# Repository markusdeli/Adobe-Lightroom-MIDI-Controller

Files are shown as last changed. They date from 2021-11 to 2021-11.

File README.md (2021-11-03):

# Adobe-Lightroom-MIDI-Controller
Custom wireless MIDI controller for picture editing in Adobe Lightroom.
Using BLE for communication between controller and receiver. 
Color encoders can be built out of 9mm mouse encoders oder KY-040.
All .stl Files needed can be found in the folder "3D-Models".
Sofware for Interpreting MIDI signals: https://github.com/rsjaffe/MIDI2LR/releases

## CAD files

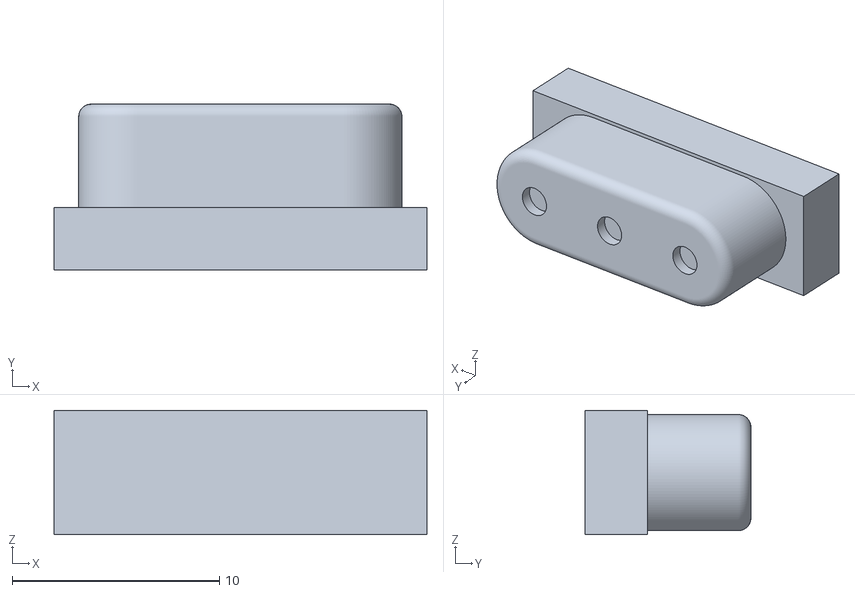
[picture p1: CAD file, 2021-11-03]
3D-models/b1.stl
18.0 x 8.00 x 6.00

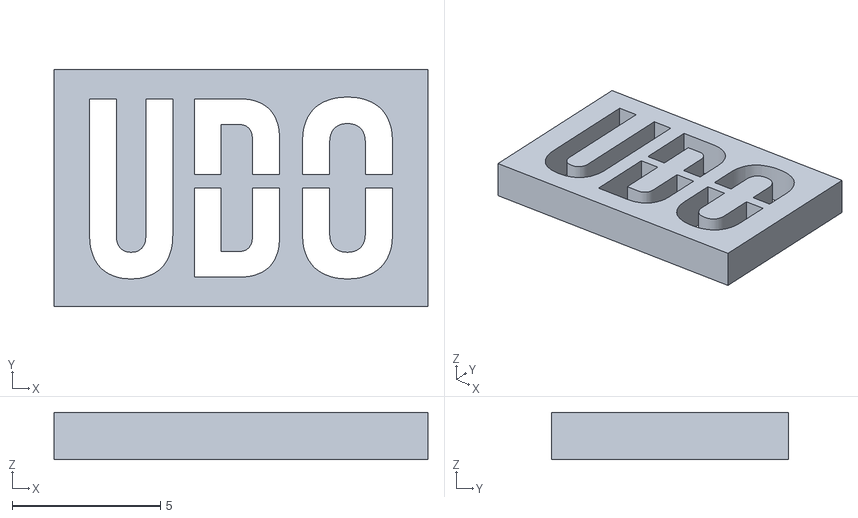
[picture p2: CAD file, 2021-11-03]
3D-models/1UDO.stl
12.6 x 8.00 x 1.60

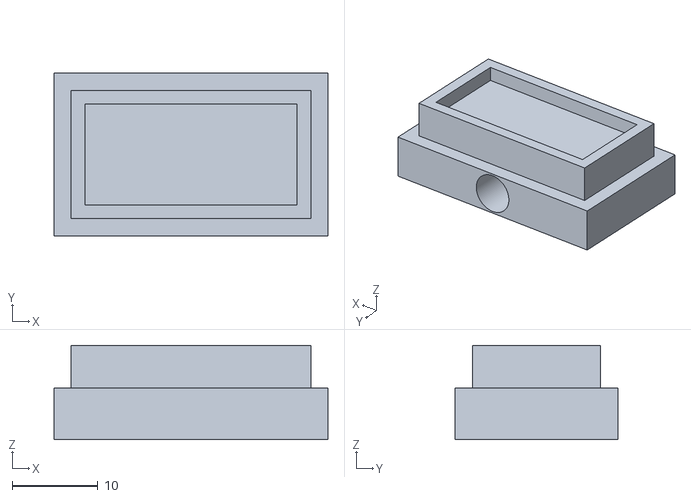
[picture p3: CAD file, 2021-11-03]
3D-models/buttonMIDimaxi.stl
32.0 x 19.0 x 11.0

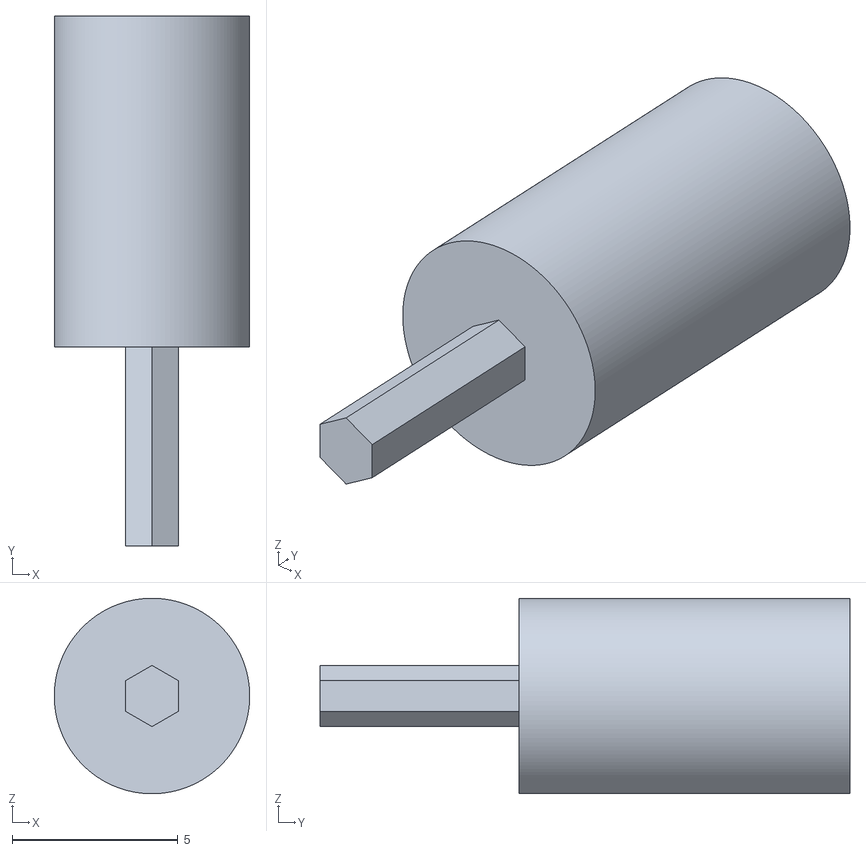
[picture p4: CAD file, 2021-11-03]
3D-models/mouse wheel shaft.stl
5.90 x 16.0 x 5.90

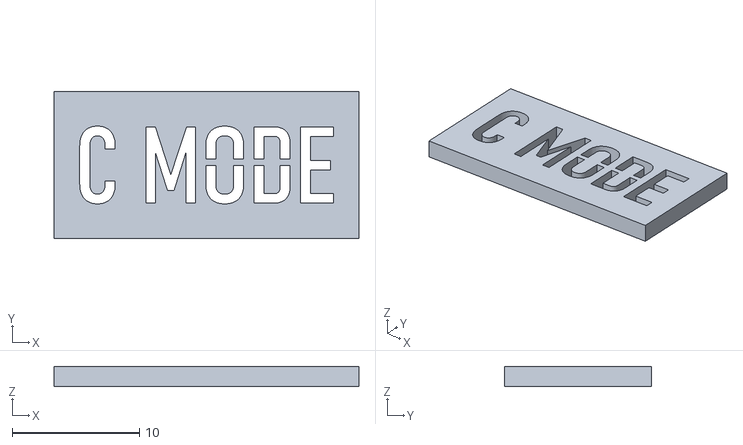
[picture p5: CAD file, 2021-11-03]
3D-models/1CMODE.stl
24.0 x 11.6 x 1.60

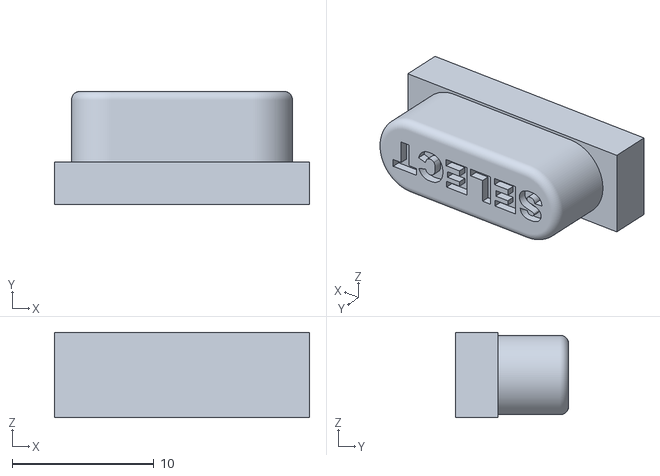
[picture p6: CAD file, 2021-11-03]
3D-models/b3.stl
18.0 x 8.00 x 6.00

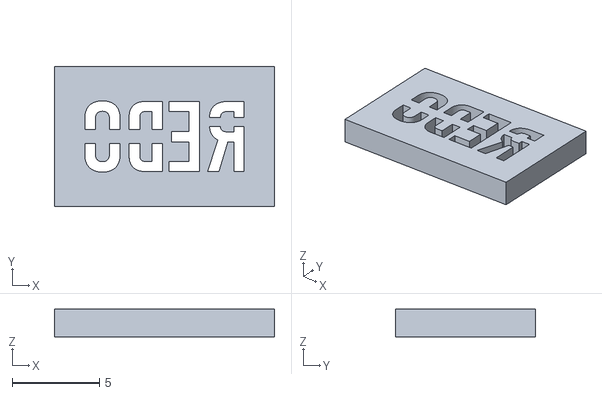
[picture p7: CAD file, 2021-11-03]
3D-models/redoMIDI.stl
12.6 x 8.00 x 1.60

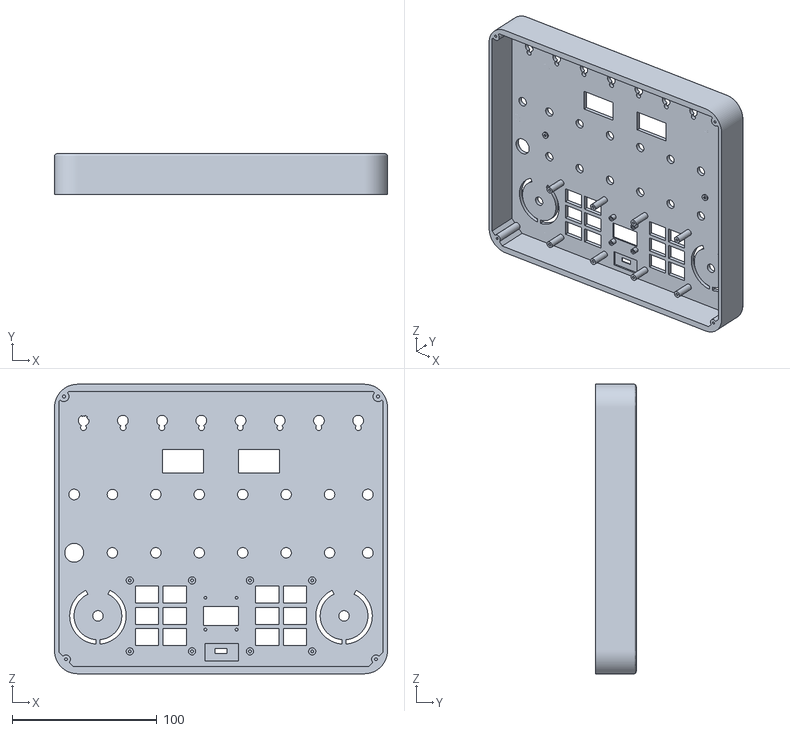
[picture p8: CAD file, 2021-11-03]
3D-models/midiv8.stl
230.0 x 28.0 x 200.0

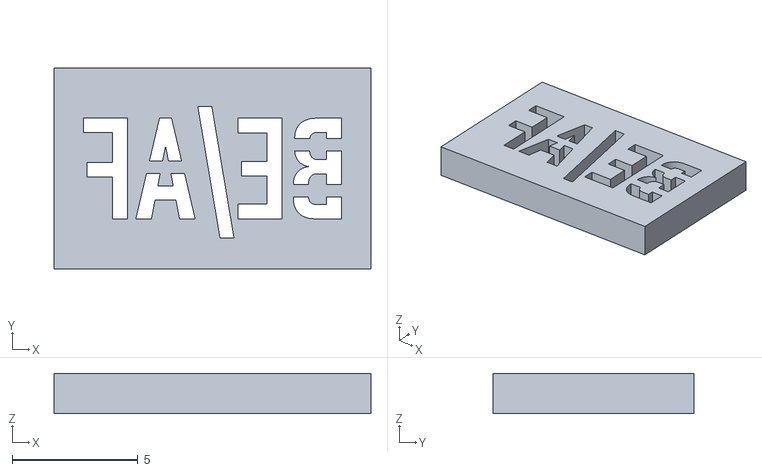
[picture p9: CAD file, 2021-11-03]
3D-models/beafMIDI.stl
12.6 x 8.00 x 1.60

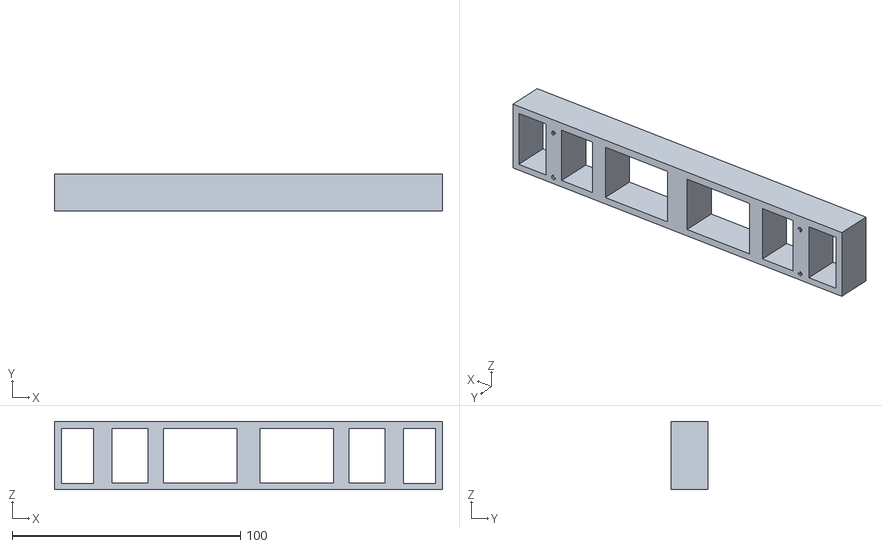
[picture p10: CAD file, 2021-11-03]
3D-models/block.stl
170.0 x 16.0 x 30.0

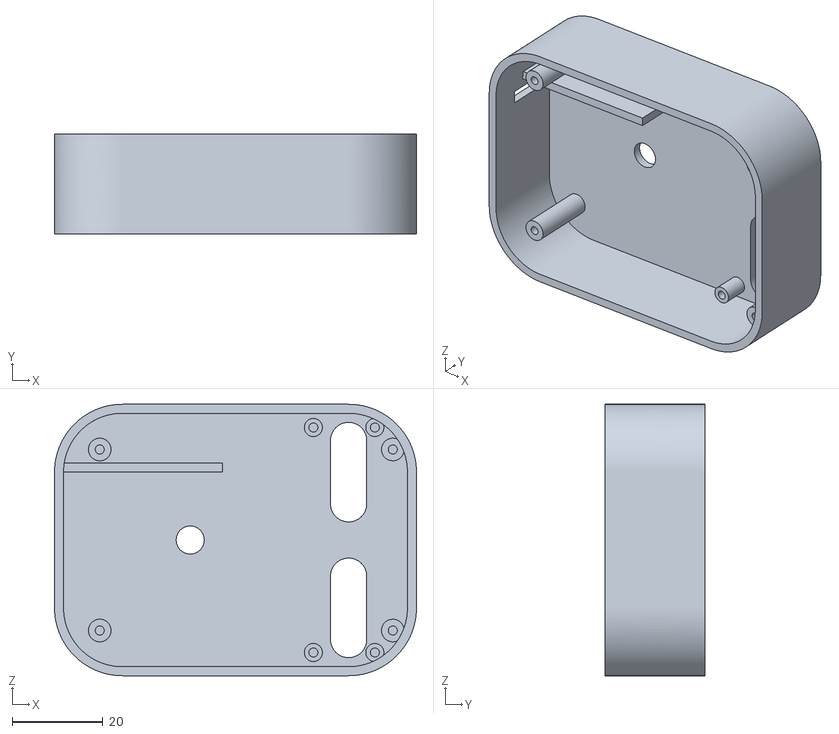
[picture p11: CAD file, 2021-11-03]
3D-models/topPiece.stl
80.0 x 22.0 x 60.0

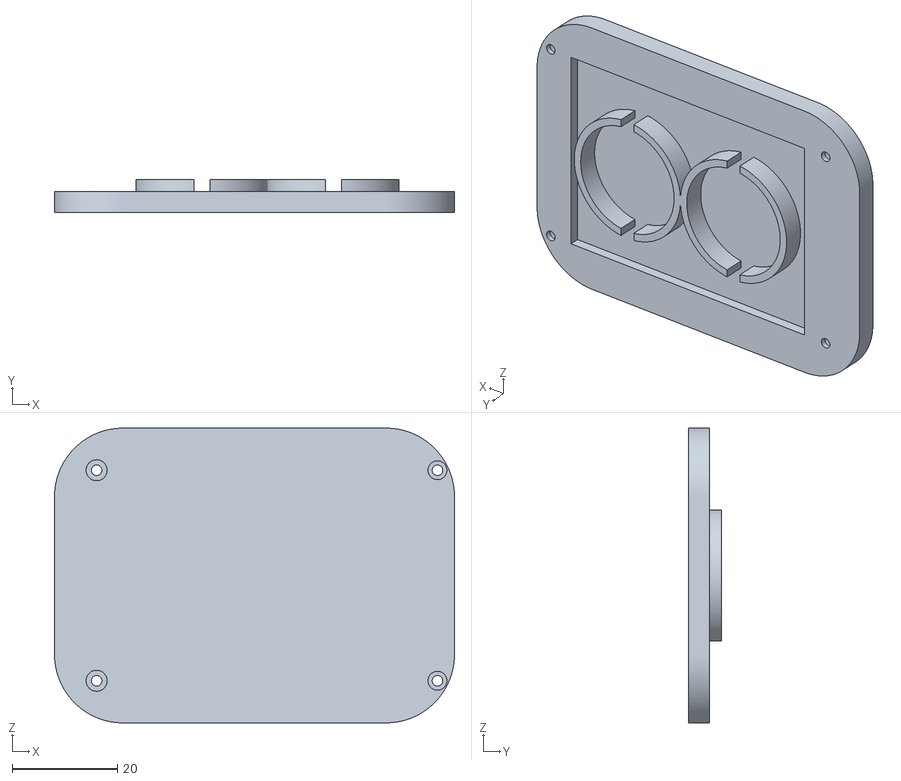
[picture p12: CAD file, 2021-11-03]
3D-models/botomPiece.stl
76.0 x 6.20 x 56.0

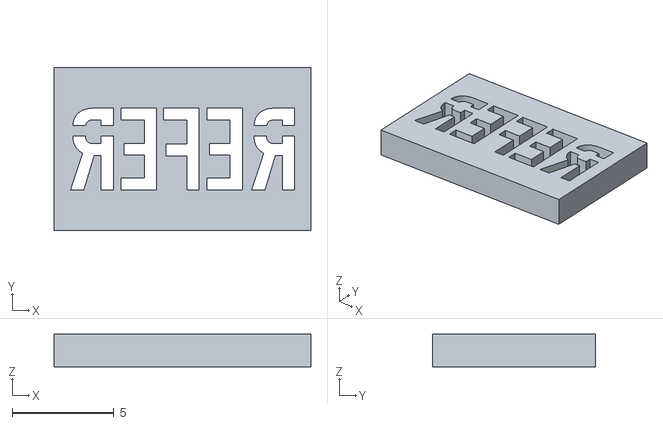
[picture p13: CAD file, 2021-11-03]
3D-models/referMIDI.stl
12.6 x 8.00 x 1.60

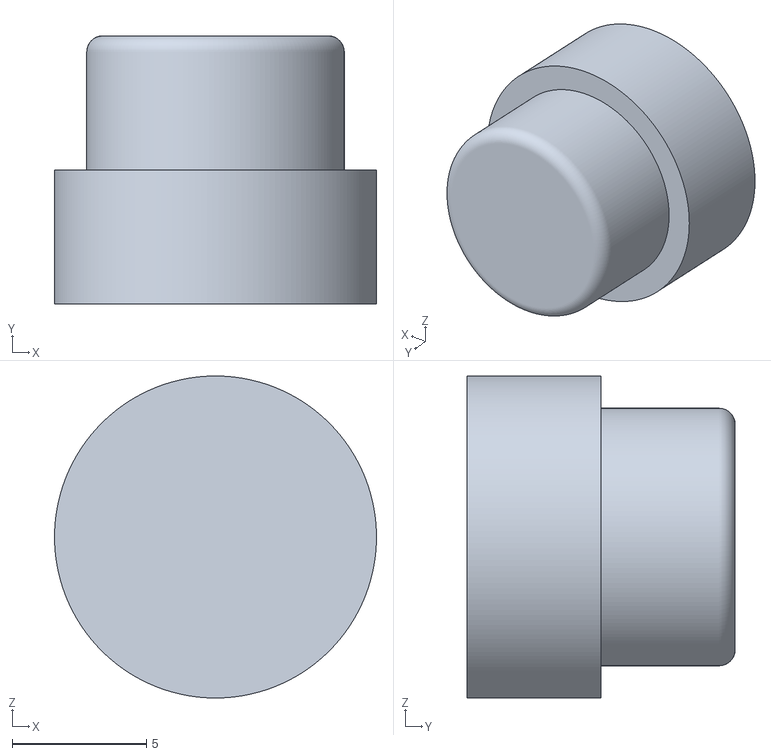
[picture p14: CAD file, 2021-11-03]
3D-models/button.stl
12.0 x 10.0 x 12.0

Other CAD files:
3D-models/1BEF.stl
3D-models/PAS.stl
3D-models/1MODE.stl
3D-models/DongleBottom.stl
3D-models/1M1.stl
3D-models/1M2.stl
3D-models/1RDO.stl
3D-models/1REF.stl
3D-models/BRU.stl
3D-models/BW.stl
3D-models/COP.stl
3D-models/DongleTop.stl
3D-models/InlayTopMIDI.stl
3D-models/RAD.stl
3D-models/REP.stl
3D-models/b2.stl
3D-models/buttonRotary.stl
3D-models/buttonklein.stl
3D-models/buttonnichtsoklein.stl
3D-models/color encoder.stl
3D-models/encoderKnobMaxiMIDI.stl
3D-models/encoderMAXIMIDI.stl
3D-models/encoderbracketmidi.stl
3D-models/encoderfillMIDI.stl
3D-models/fillMIDIEnc.stl
3D-models/inlayWheelLEDMIDI.stl
3D-models/kabelkammmidi.stl
3D-models/midicasetop.stl
3D-models/midicontrollerv1.stl
3D-models/midiencoderwheel.stl
3D-models/mouseshaftMIDI.stl
3D-models/stütze buttonMIDI.stl
3D-models/undoMIDI.stl

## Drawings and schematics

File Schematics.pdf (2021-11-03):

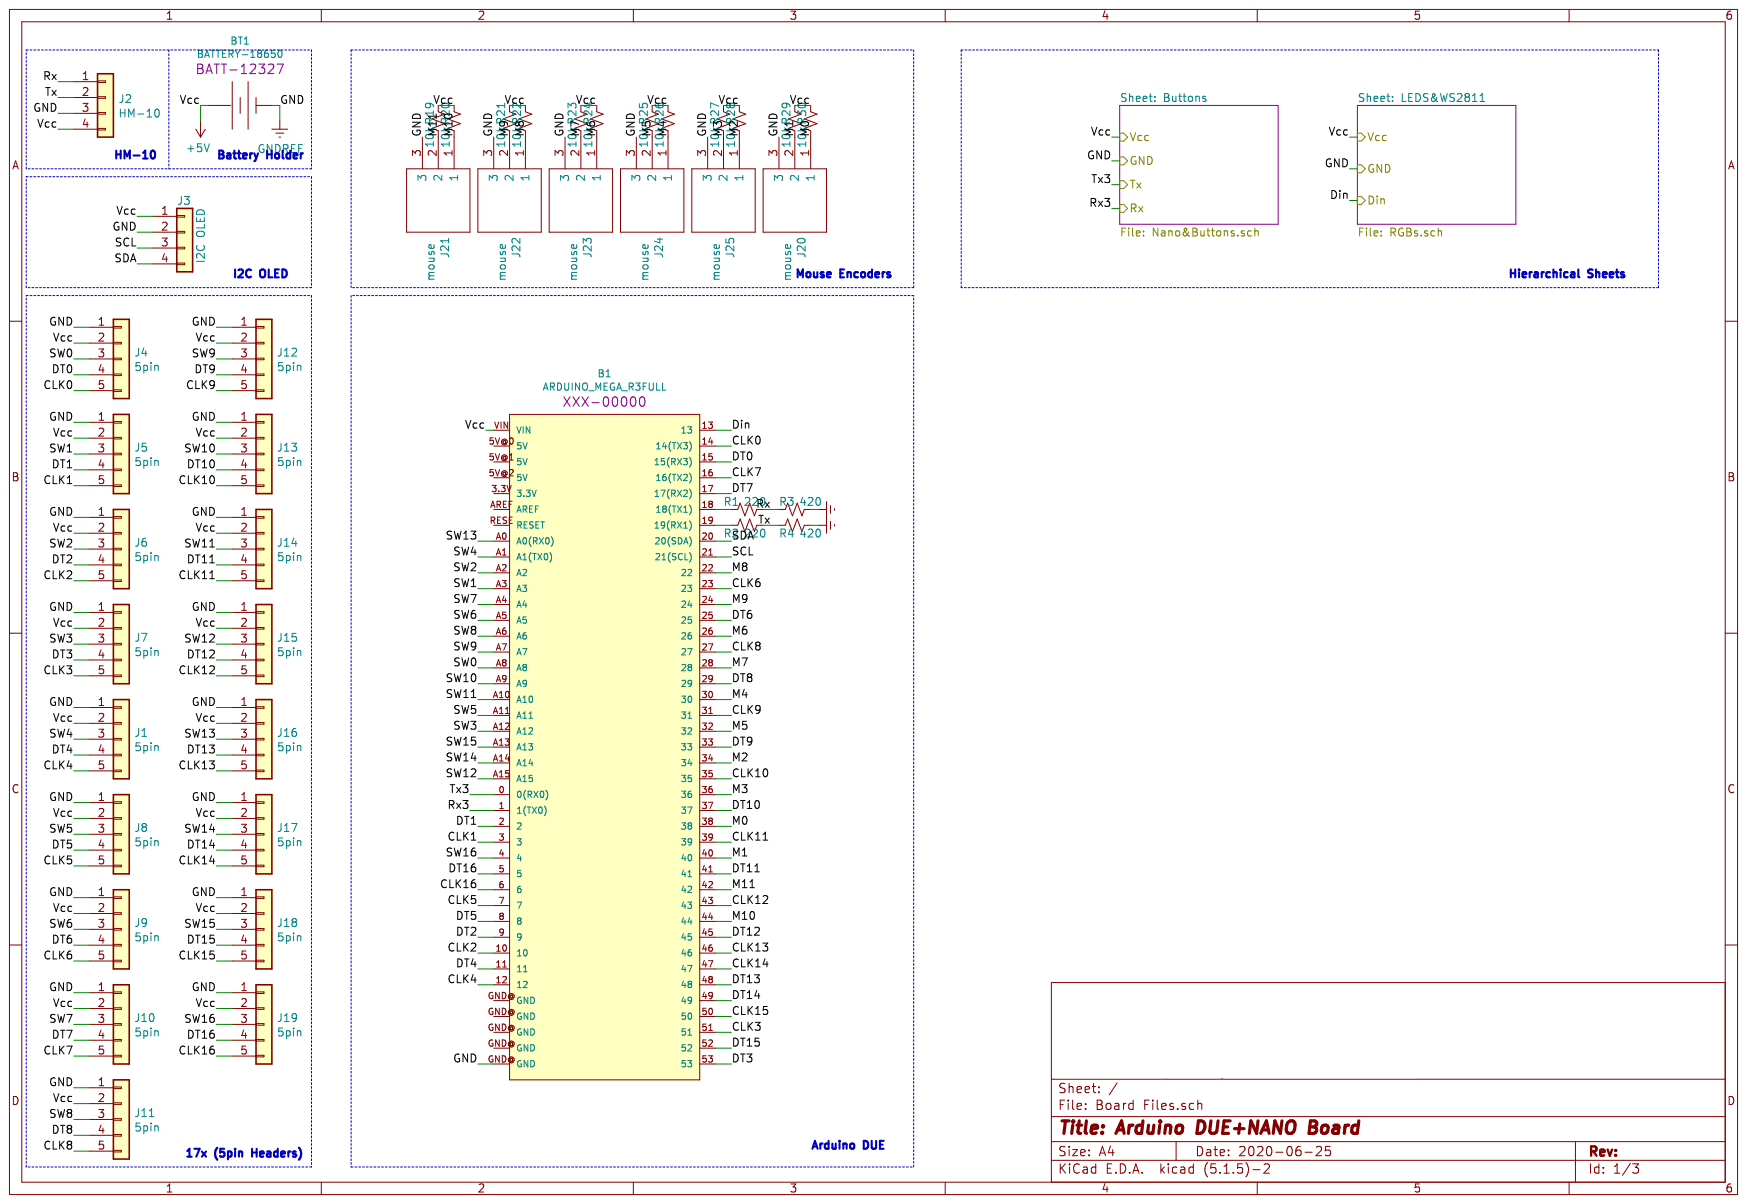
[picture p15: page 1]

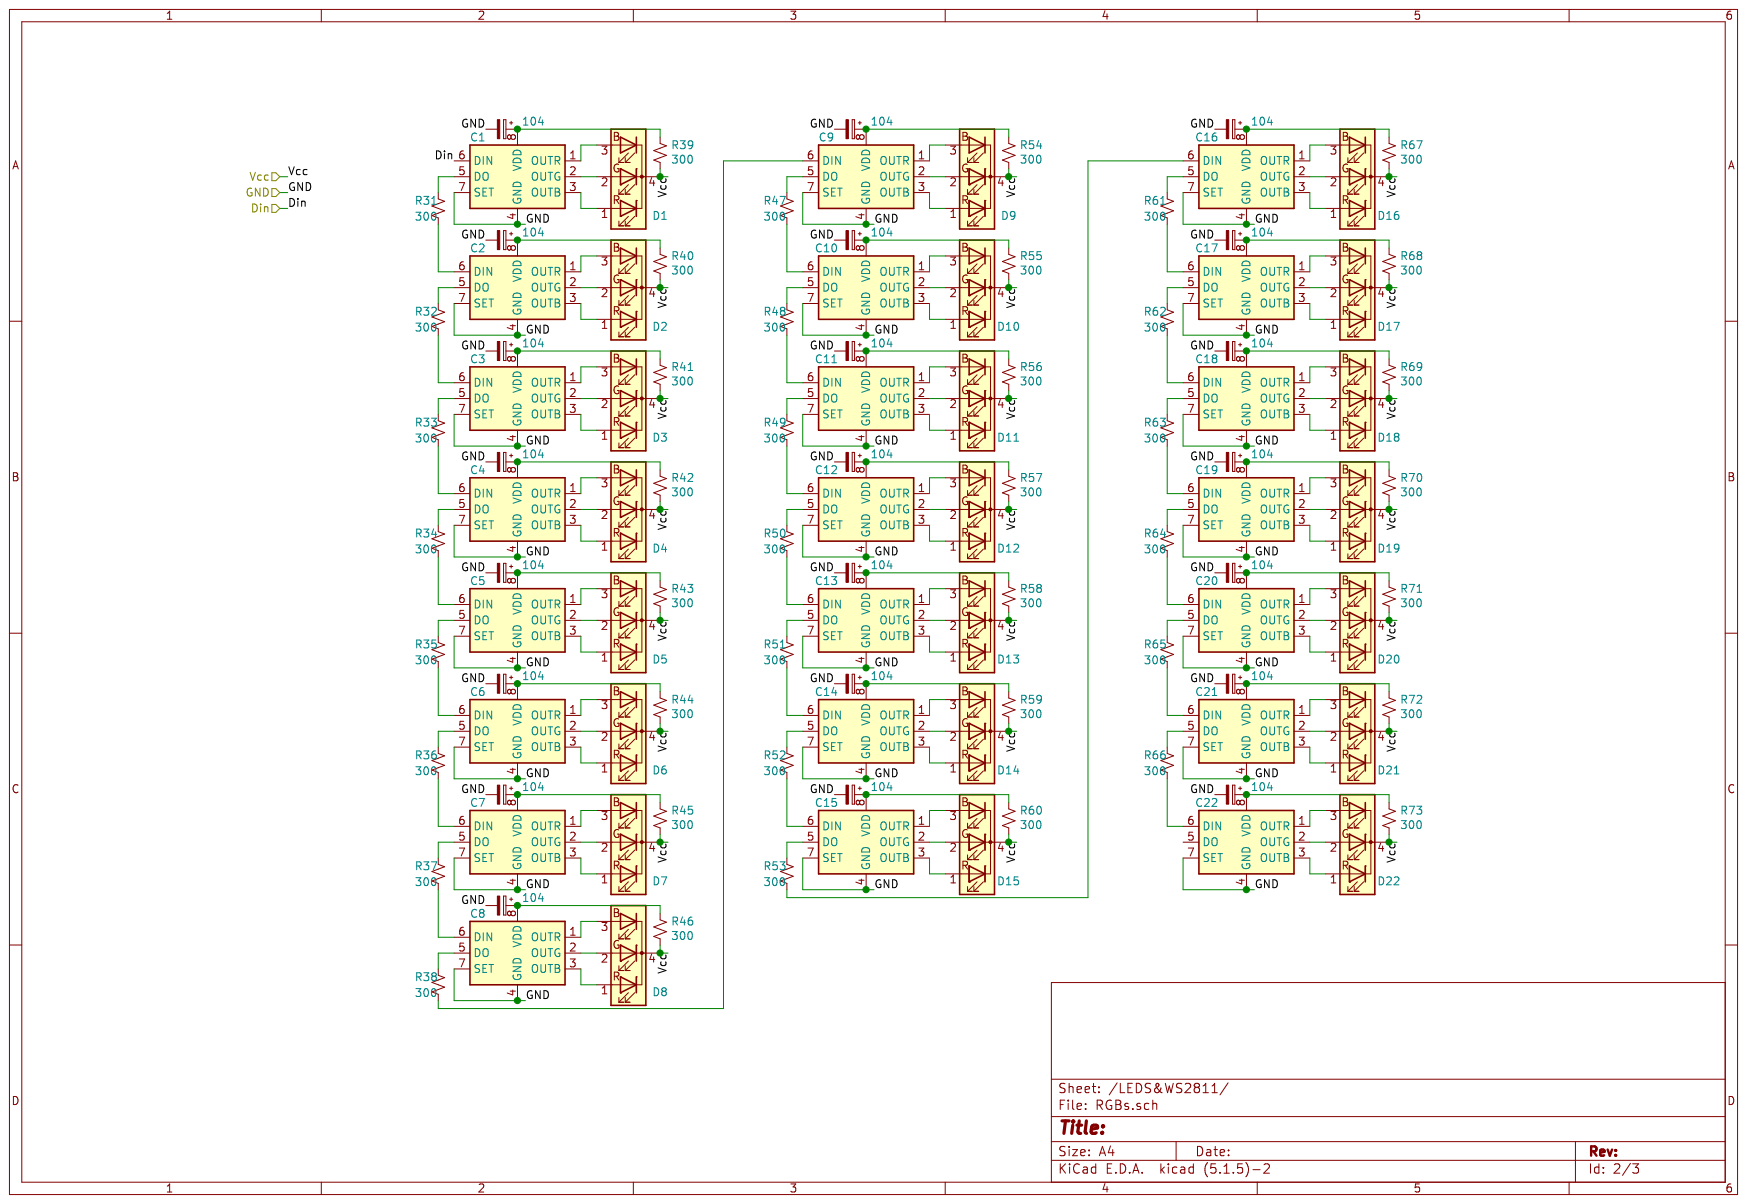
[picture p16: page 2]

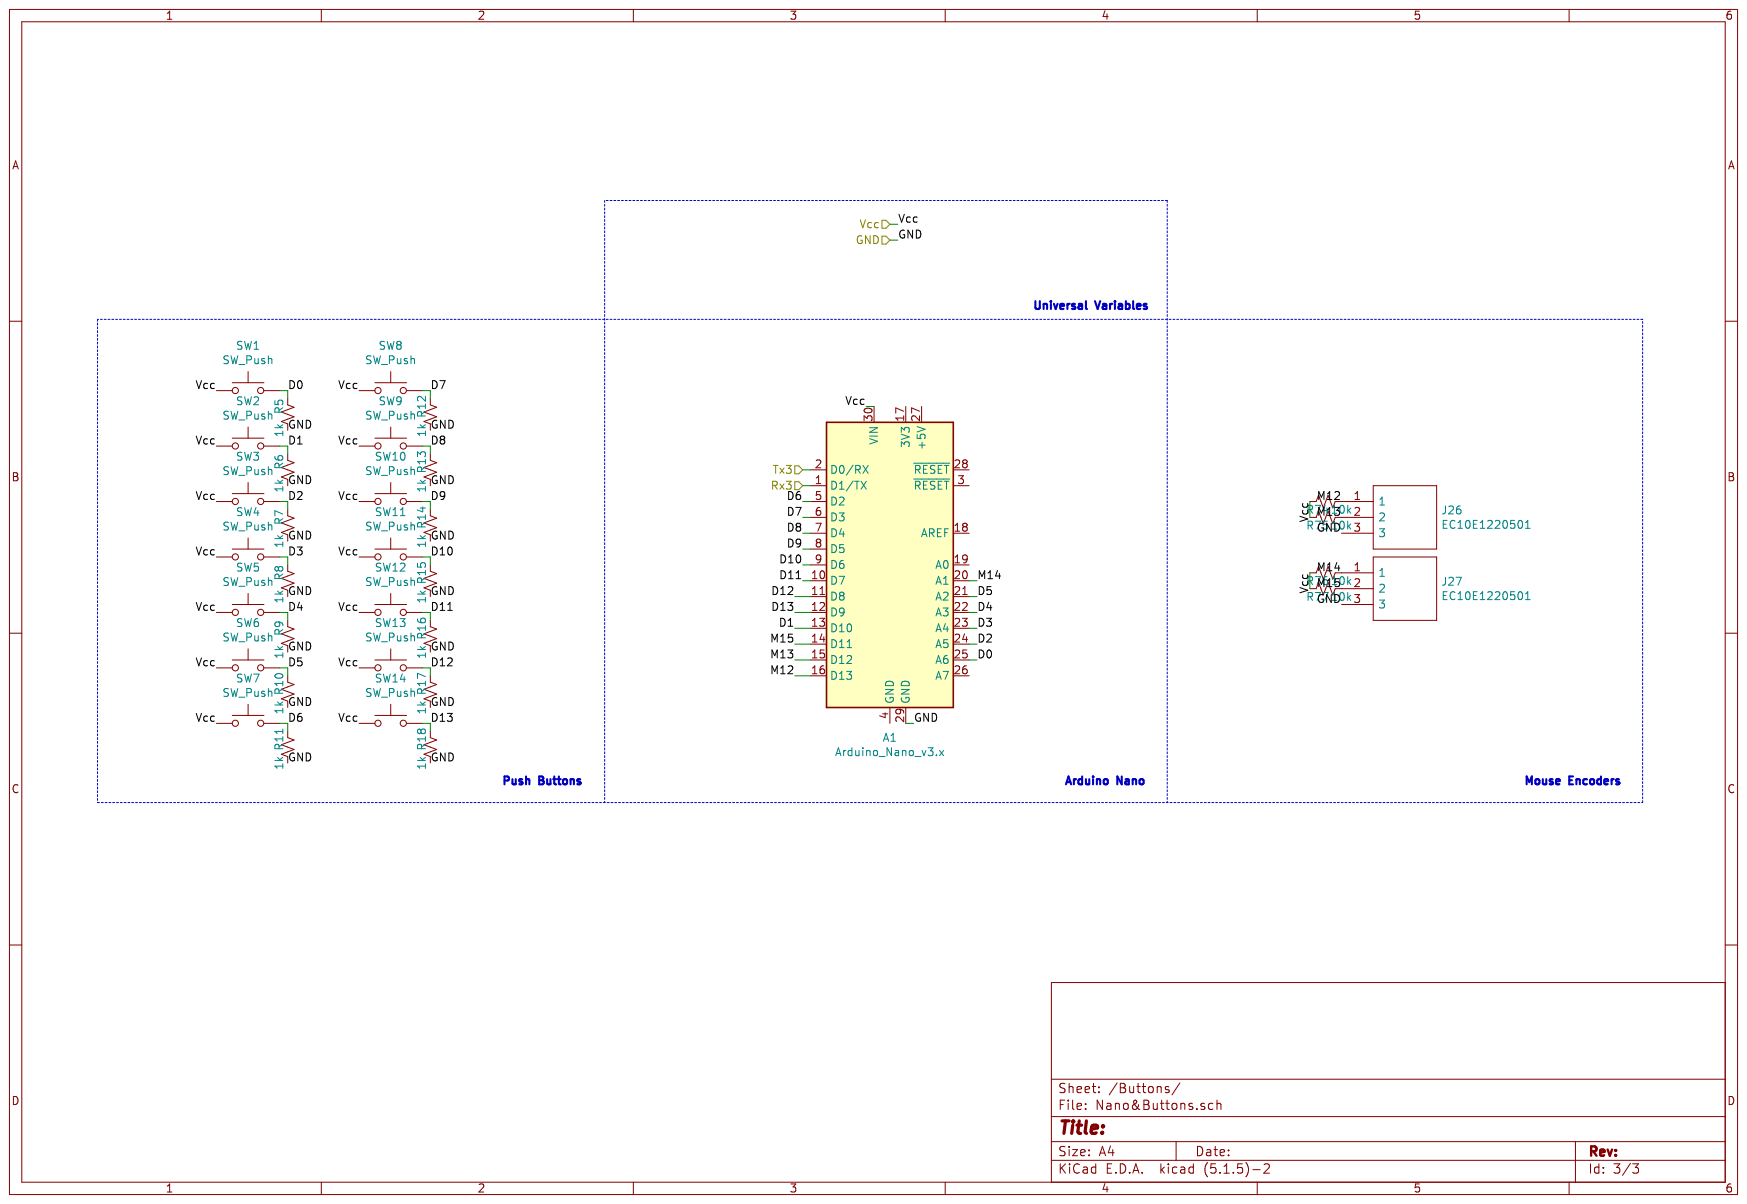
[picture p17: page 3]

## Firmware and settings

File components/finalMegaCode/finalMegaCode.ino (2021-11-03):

#include <Adafruit_NeoPixel.h>
#include <Bounce2.h>
#include <Encoder.h>  
#include <SoftwareSerial.h>
#include <SPI.h>
#include <Wire.h>
#include <Adafruit_GFX.h>
#include <Adafruit_SSD1306.h>
//SoftwareSerial mySerial(A8, A9); // RX, TX


#define SCREEN_WIDTH 128 // OLED display width, in pixels
#define SCREEN_HEIGHT 64 // OLED display height, in pixels

Adafruit_SSD1306 display(SCREEN_WIDTH, SCREEN_HEIGHT, &Wire, -1);

String msgString = "";

bool displayCheck = false;

long timer;
//All clickable Encoders

//Temperatur
const int CLK_TEMP = 6;      
const int DT_TEMP = 5;
int SW_TEMP = 4;       
long oldPos_TEMP = -999;
bool enTEMP = false;
Bounce ENC_TEMP = Bounce(SW_TEMP, 10);
Encoder EncoderTEMP(DT_TEMP,CLK_TEMP);
int encoderValueTEMP;

//Hue
const int CLK_HUE = 10;      
const int DT_HUE = 9;
int SW_HUE = A2;       
long oldPos_HUE = -999;
bool enHUE = false;
Bounce ENC_HUE = Bounce(SW_HUE, 10);
Encoder EncoderHUE(DT_HUE,CLK_HUE);
int encoderValueHUE;

//Belichtung
const int CLK_BEL = 12;    
const int DT_BEL = 11;
int SW_BEL = A1;       
long oldPos_BEL = -999;
bool enBEL = false;
Bounce ENC_BEL = Bounce(SW_BEL, 10);
Encoder EncoderBEL(DT_BEL,CLK_BEL);
int encoderValueBEL;

//Kontrast
const int CLK_KON = 23;      
const int DT_KON = 25;
int SW_KON = A5;       
long oldPos_KON = -999;
bool enKON = false;
Bounce ENC_KON = Bounce(SW_KON, 10);
Encoder EncoderKON(DT_KON,CLK_KON);
int encoderValueKON;

//Lichter
const int CLK_LI = 31;      
const int DT_LI = 33;
int SW_LI = A7;       
long oldPos_LI = -999;
bool enLI = false;
Bounce ENC_LI = Bounce(SW_LI, 10);
Encoder EncoderLI(DT_LI,CLK_LI);
int encoderValueLI;

//Tiefen
const int CLK_TI = 39;      
const int DT_TI = 41;
int SW_TI = A10;       
long oldPos_TI = -999;
bool enTI = false;
Bounce ENC_TI = Bounce(SW_TI, 10);
Encoder EncoderTI(DT_TI,CLK_TI);
int encoderValueTI;

//Weiß
const int CLK_WE = A8;      
const int DT_WE = A9;
int SW_WE = A4;       
long oldPos_WE = -999;
bool enWE = false;
Bounce ENC_WE = Bounce(SW_WE, 10);
Encoder EncoderWE(DT_WE,CLK_WE);
int encoderValueWE;

//Schwarz
const int CLK_SW = 43;      
const int DT_SW = 45;
int SW_SW = A15;       
long oldPos_SW = -999;
bool enSW = false;
Bounce ENC_SW = Bounce(SW_SW, 10);
Encoder EncoderSW(DT_SW,CLK_SW);
int encoderValueSW;

//System1
const int CLK_S1 = 3;     
const int DT_S1 = 2; 
int SW_S1 = A3;      
long oldPos_S1 = -999;
bool enS1 = false;
Bounce ENC_S1 = Bounce(SW_S1, 10);
Encoder EncoderS1(DT_S1,CLK_S1);
int encoderValueS1;

//System2
const int CLK_S2 = 50;      
const int DT_S2 = 52;
int SW_S2 = A13;       
long oldPos_S2 = -999;
bool enS2 = false;
Bounce ENC_S2 = Bounce(SW_S2, 10);
Encoder EncoderS2(DT_S2,CLK_S2);
int encoderValueS2;

//Struktur
const int CLK_ST = 46;      
const int DT_ST = 48;
int SW_ST = A0;       
long oldPos_ST = -999;
bool enST = false;
Bounce ENC_ST = Bounce(SW_ST, 10);
Encoder EncoderST(DT_ST,CLK_ST);
int encoderValueST;

//Klarheit
const int CLK_KL = 47;      
const int DT_KL = 49;
int SW_KL = A14;       
long oldPos_KL = -999;
bool enKL = false;
Bounce ENC_KL = Bounce(SW_KL, 10);
Encoder EncoderKL(DT_KL,CLK_KL);
int encoderValueKL;

//Dunst
const int CLK_DU = 51;      
const int DT_DU = 53;
int SW_DU = A12;       
long oldPos_DU = -999;
bool enDU = false;
Bounce ENC_DU = Bounce(SW_DU, 10);
Encoder EncoderDU(DT_DU,CLK_DU);
int encoderValueDU;

//Dynamik
const int CLK_DY = 14;      
const int DT_DY = 15;
//int SW_DY = A8;       
long oldPos_DY = -999;
//bool enDY = false;
//Bounce ENC_DY = Bounce(SW_DY, 10);
Encoder EncoderDY(DT_DY,CLK_DY);
int encoderValueDY;

//Sättigung
const int CLK_SA = 35;      
const int DT_SA = 37;
//int SW_SA = A9;       
long oldPos_SA = -999;
//bool enSA = false;
//Bounce ENC_SA = Bounce(SW_SA, 10);
Encoder EncoderSA(DT_SA,CLK_SA);
int encoderValueSA;

//Verzerrung
const int CLK_VER = 27;      
const int DT_VER = 29;
int SW_VER = A6;       
long oldPos_VER = -999;
bool enVER = false;
Bounce ENC_VER = Bounce(SW_VER, 10);
Encoder EncoderVER(DT_VER,CLK_VER);
int encoderValueVER;

//System3
const int CLK_S3 = 7;      
const int DT_S3 = 8;
int SW_S3 = A11;       
long oldPos_S3 = -999;
bool enS3 = false;
Bounce ENC_S3 = Bounce(SW_S3, 10);
Encoder EncoderS3(DT_S3,CLK_S3);
int encoderValueS3;


//Non clickable Encoders

//J20
const int CLK_J20 = 40;      
const int DT_J20 = 38;
long oldPos_J20 = -999;
Encoder EncoderJ20(DT_J20,CLK_J20);
int encoderValueJ20;

//J21
const int CLK_J21 = 42;      
const int DT_J21 = 44;
long oldPos_J21 = -999;
Encoder EncoderJ21(DT_J21,CLK_J21);
int encoderValueJ21;

//J22
const int CLK_J22 = 24;      
const int DT_J22 = 22;
long oldPos_J22 = -999;
Encoder EncoderJ22(DT_J22,CLK_J22);
int encoderValueJ22;

//J23
const int CLK_J23 = 28;      
const int DT_J23 = 26;
long oldPos_J23 = -999;
Encoder EncoderJ23(DT_J23,CLK_J23);
int encoderValueJ23;

//J24
const int CLK_J24 = 32;      
const int DT_J24 = 30;
long oldPos_J24 = -999;
Encoder EncoderJ24(DT_J24,CLK_J24);
int encoderValueJ24;

//J25
const int CLK_J25 = 36;
const int DT_J25 = 34;
long oldPos_J25 = -999;
Encoder EncoderJ25(DT_J25,CLK_J25);
int encoderValueJ25;

//LED Config

#define PIN  13
#define NUMPIXELS 48

Adafruit_NeoPixel pixels = Adafruit_NeoPixel(NUMPIXELS, PIN, NEO_GRB + NEO_KHZ800);


//Some Colors

int red[3] = {0,255, 0};
int green[3] = {255, 0, 0};
int blue[3] = {0, 0, 255};
int orange[3] = {60, 255, 0};
int yellow[3] = {110, 140, 0};
int purple[3] = {0, 110, 200};
int white[3] = {255, 255, 255};
int aqua[3] = {30, 30, 200};
int magenta[3] = {0, 80, 180};
int colorSetLeft[][3] = { {230, 130, 0},{0, 0, 250}, {0, 0, 150}, {0, 0, 60}, {0, 0, 20}, {90, 90, 120}, {90, 90, 90}, {90, 90, 90}, {30, 17, 0}, {100, 50, 0}, {150, 80, 0}, {180, 110, 0}, };
int colorSetRight[][3] = { {0, 250, 0}, {0, 160, 0}, {0, 100, 0}, {0, 60, 0}, {90, 150, 90}, {90, 90, 90}, {90, 90, 90}, {120, 90, 130}, {10, 0, 18}, {30, 0, 56}, {120, 0, 200}, {100, 0, 200}};
//int colorEncoder[][3] = {{0,255, 0}, {60, 255, 0}, {110, 140, 0}, {255, 0, 0}, {120, 40, 120}, {0, 0, 255}, {0, 100, 180}, {0, 180, 90}};
int colorEncoder[][3] = { {0, 180, 90},{0, 100, 180},{0, 0, 255},{120, 40, 120}, {255, 0, 0}, {110, 140, 0}, {60, 255, 0},{0,255, 0}};


int modeEncoder = 0;
int modeColorEncoder = 0;
const int modeLimit = 2;
const int modeLimitColor = 3;

int modeValues[12][modeLimit] = {};
int modeValuesRingEncoder[5] = {};
int modeValuesColor[6][modeLimitColor] = {};



byte batteryState;

void testdrawline() {
  int16_t i;

  display.clearDisplay(); // Clear display buffer

  for(i=0; i<display.width(); i+=4) {
    display.drawLine(0, 0, i, display.height()-1, SSD1306_WHITE);
    display.display(); // Update screen with each newly-drawn line
    delay(1);
  }
  for(i=0; i<display.height(); i+=4) {
    display.drawLine(0, 0, display.width()-1, i, SSD1306_WHITE);
    display.display();
    delay(1);
  }
  delay(50);

  display.clearDisplay();

  for(i=0; i<display.width(); i+=4) {
    display.drawLine(0, display.height()-1, i, 0, SSD1306_WHITE);
    display.display();
    delay(1);
  }
  for(i=display.height()-1; i>=0; i-=4) {
    display.drawLine(0, display.height()-1, display.width()-1, i, SSD1306_WHITE);
    display.display();
    delay(1);
  }
  delay(50);

  display.clearDisplay();

  for(i=display.width()-1; i>=0; i-=4) {
    display.drawLine(display.width()-1, display.height()-1, i, 0, SSD1306_WHITE);
    display.display();
    delay(1);
  }
  for(i=display.height()-1; i>=0; i-=4) {
    display.drawLine(display.width()-1, display.height()-1, 0, i, SSD1306_WHITE);
    display.display();
    delay(1);
  }
  delay(50);

  display.clearDisplay();

  for(i=0; i<display.height(); i+=4) {
    display.drawLine(display.width()-1, 0, 0, i, SSD1306_WHITE);
    display.display();
    delay(1);
  }
  for(i=0; i<display.width(); i+=4) {
    display.drawLine(display.width()-1, 0, i, display.height()-1, SSD1306_WHITE);
    display.display();
    delay(1);
  }

  delay(100); // Pause for 2 seconds
}

void testdrawrect(void) {
  display.clearDisplay();

  for(int16_t i=0; i<display.height()/2; i+=2) {
    display.drawRect(i, i, display.width()-2*i, display.height()-2*i, SSD1306_WHITE);
    display.display(); // Update screen with each newly-drawn rectangle
    delay(1);
  }

  delay(100);
}

void rainbow(int wait) {
  // Hue of first pixel runs 5 complete loops through the color wheel.
  // Color wheel has a range of 65536 but it's OK if we roll over, so
  // just count from 0 to 5*65536. Adding 256 to firstPixelHue each time
  // means we'll make 5*65536/256 = 1280 passes through this outer loop:
  for(long firstPixelHue = 0; firstPixelHue < 5*65536; firstPixelHue += 256) {
    for(int i=0; i<pixels.numPixels(); i++) { // For each pixel in strip...
      // Offset pixel hue by an amount to make one full revolution of the
      // color wheel (range of 65536) along the length of the strip
      // (strip.numPixels() steps):
      int pixelHue = firstPixelHue + (i * 65536L / pixels.numPixels());
      // strip.ColorHSV() can take 1 or 3 arguments: a hue (0 to 65535) or
      // optionally add saturation and value (brightness) (each 0 to 255).
      // Here we're using just the single-argument hue variant. The result
      // is passed through strip.gamma32() to provide 'truer' colors
      // before assigning to each pixel:
      pixels.setPixelColor(i, pixels.gamma32(pixels.ColorHSV(pixelHue)));
    }
    pixels.show(); // Update strip with new contents
    delay(wait);  // Pause for a moment
  }
}

void printHomeScreen(String message) {
    display.clearDisplay();
    display.setTextSize(1); 
    display.setTextColor(WHITE);
    display.setCursor(1,56);
    display.println("General Admiral MIDI");
    display.setCursor(1,20);
    display.setTextSize(2); 
    display.println(message);
    display.display();
}


void setTwelveButtonsColor(int rgb[]){
  for(int i = 0; i < 12; i++){
    pixels.setPixelColor(i, pixels.Color(rgb[0], rgb[1], rgb[2]));
    pixels.show();
  }
}

void setColorEncoders(int colors[][3]){
  int count = 0;
  for(int i = 14; i < 22; i++){
    pixels.setPixelColor(i, pixels.Color(colors[count][0], colors[count][1], colors[count][2]));
    pixels.show();
    count++;
  }
}

void setLeftColorWheel(int colors[][3]){
  int count = 0;
  for(int i = 22; i < 34; i++){
    pixels.setPixelColor(i, pixels.Color(colors[count][0], colors[count][1], colors[count][2]));
    pixels.show();
    count++;
  }
}

void setRightColorWheel(int colors[][3]){
  int count = 0;
  for(int i = 34; i < 46; i++){
    pixels.setPixelColor(i, pixels.Color(colors[count][0], colors[count][1], colors[count][2]));
    pixels.show();
    count++;
  }
}

void sendMidiMsg(byte channel, byte mode, byte velocity){
  byte tmp[] = {0x0B, channel, mode, velocity};
  Serial1.write(tmp, 4);
}

void getMidiMsg(byte msg[]){
  Serial.println("Wir sind in getMidiMsg");
  if(msg[2] < 0x05){
    modeValuesRingEncoder[msg[2]] = msg[3];
  }
  else{
    if(msg[2] > 46){
      Serial2.write(msg, 4);   
    }
    else{
      modeValues[msg[2]][modeEncoder] = msg[3];
    }
  }
}

void readEncoderTEMP(){    
  long neuePosition; 
  encoderValueTEMP = modeValuesRingEncoder[0];
  neuePosition = EncoderTEMP.read();  
    if (neuePosition != oldPos_TEMP)
    {
      if (neuePosition > oldPos_TEMP + 3){
        if(encoderValueTEMP < 127){
          encoderValueTEMP++;
        }           
        sendMidiMsg(0xB0,0, encoderValueTEMP);            
        oldPos_TEMP = neuePosition;  
      }
      else if(neuePosition < oldPos_TEMP - 3){
        if(encoderValueTEMP > 0){              
          encoderValueTEMP--;
        }
        sendMidiMsg(0xB0, 0, encoderValueTEMP);            
        oldPos_TEMP = neuePosition;              
      }
      modeValuesRingEncoder[0] = encoderValueTEMP;   
      msgString = "Temperatur";
      displayCheck = true;  
    }
}

void readEncoderHUE(){    
  long neuePosition; 
  encoderValueHUE = modeValuesRingEncoder[1];
  neuePosition = EncoderHUE.read();  
    if (neuePosition != oldPos_HUE)
    {
      if (neuePosition > oldPos_HUE + 3){
        if(encoderValueHUE < 127){
          encoderValueHUE++;
        }           
        sendMidiMsg(0xB0, 0x01, encoderValueHUE);            
        oldPos_HUE = neuePosition;  
      }
      else if(neuePosition < oldPos_HUE - 3){
        if(encoderValueHUE > 0){              
          encoderValueHUE--;
        }
        sendMidiMsg(0xB0, 0x01, encoderValueHUE);            
        oldPos_HUE = neuePosition;              
      }
     modeValuesRingEncoder[1] = encoderValueHUE;
     msgString = "Toenung";
     displayCheck = true;  
    }
}

void readEncoderS1(){    
  long neuePosition; 
  encoderValueS1 = modeValuesRingEncoder[2];
  neuePosition = EncoderS1.read();  
    if (neuePosition != oldPos_S1)
    {
      if (neuePosition > oldPos_S1 + 3){
        if(encoderValueS1 < 127){
          encoderValueS1++;
        }           
        sendMidiMsg(0xB0, 0x02, 127);            
        oldPos_S1 = neuePosition;  
      }
      else if(neuePosition < oldPos_S1 - 3){
        if(encoderValueS1 > 0){              
          encoderValueS1--;
        }
        sendMidiMsg(0xB0, 0x70, 127);            
        oldPos_S1 = neuePosition;              
      }
     modeValuesRingEncoder[2] = encoderValueS1;  
    }
}

void readEncoderS2(){    
  long neuePosition; 
  encoderValueS2 = modeValuesRingEncoder[3];
  neuePosition = EncoderS2.read();  
    if (neuePosition != oldPos_S2)
    {
      if (neuePosition > oldPos_S2 + 3){
        if(encoderValueS2 < 127){
          encoderValueS2++;
        }           
        sendMidiMsg(0xB0, 0x03, 127);            
        oldPos_S2 = neuePosition;  
      }
      else if(neuePosition < oldPos_S2 - 3){
        if(encoderValueS2 > 0){              
          encoderValueS2--;
        }
        sendMidiMsg(0xB0, 0x69, 127);            
        oldPos_S2 = neuePosition;              
      }
     modeValuesRingEncoder[3] = encoderValueS2;  
    }
}

void readEncoderS3(){    
  long neuePosition; 
  encoderValueS3 = modeValuesRingEncoder[4];
  neuePosition = EncoderS3.read();  
    if (neuePosition != oldPos_S3)
    {
      if (neuePosition > oldPos_S3 + 3){
        if(encoderValueS3 < 127){
          encoderValueS3++;
        }           
        sendMidiMsg(0xB0, 0x04, encoderValueS3);            
        oldPos_S3 = neuePosition;  
      }
      else if(neuePosition < oldPos_S3 - 3){
        if(encoderValueS3 > 0){              
          encoderValueS3--;
        }
        sendMidiMsg(0xB0, 0x04, encoderValueS3);            
        oldPos_S3 = neuePosition;              
      }
     modeValuesRingEncoder[4] = encoderValueS3;  
    }
}

void readEncoderBEL(){    
  long neuePosition; 
  encoderValueBEL = modeValues[0][modeEncoder];
  neuePosition = EncoderBEL.read();  
    if (neuePosition != oldPos_BEL)
    {
      if (neuePosition > oldPos_BEL + 3){
        if(encoderValueBEL < 127){
          encoderValueBEL++;
        }           
        sendMidiMsg(0xB0, 0x05 + modeEncoder, encoderValueBEL);            
        oldPos_BEL = neuePosition;  
      }
      else if(neuePosition < oldPos_BEL - 3){
        if(encoderValueBEL > 0){              
          encoderValueBEL--;
        }
        sendMidiMsg(0xB0, 0x05 + modeEncoder, encoderValueBEL);            
        oldPos_BEL = neuePosition;              
      }
      modeValues[0][modeEncoder] = encoderValueBEL;  
    }
}

void readEncoderKON(){    
  long neuePosition; 
  encoderValueKON = modeValues[1][modeEncoder];
  neuePosition = EncoderKON.read();  
    if (neuePosition != oldPos_KON)
    {
      if (neuePosition > oldPos_KON + 3){
        if(encoderValueKON < 127){
          encoderValueKON++;
        }           
        sendMidiMsg(0xB0, 0x07 +modeEncoder, encoderValueKON);            
        oldPos_KON = neuePosition;  
      }
      else if(neuePosition < oldPos_KON - 3){
        if(encoderValueKON > 0){              
          encoderValueKON--;
        }
        sendMidiMsg(0xB0, 0x07 + modeEncoder, encoderValueKON);            
        oldPos_KON = neuePosition;              
      }
      modeValues[1][modeEncoder] = encoderValueKON;  
    }
}

void readEncoderLI(){    
  long neuePosition; 
  encoderValueLI = modeValues[2][modeEncoder];
  neuePosition = EncoderLI.read();  
    if (neuePosition != oldPos_LI)
    {
      if (neuePosition > oldPos_LI + 3){
        if(encoderValueLI < 127){
          encoderValueLI++;
        }           
        sendMidiMsg(0xB0, 0x09 +modeEncoder, encoderValueLI);            
        oldPos_LI = neuePosition;  
      }
      else if(neuePosition < oldPos_LI - 3){
        if(encoderValueLI > 0){              
          encoderValueLI--;
        }
        sendMidiMsg(0xB0, 0x09 + modeEncoder, encoderValueLI);            
        oldPos_LI = neuePosition;              
      }
      modeValues[2][modeEncoder] = encoderValueLI;  
    }
}

void readEncoderTI(){    
  long neuePosition; 
  encoderValueTI = modeValues[3][modeEncoder];
  neuePosition = EncoderTI.read();  
    if (neuePosition != oldPos_TI)
    {
      if (neuePosition > oldPos_TI + 3){
        if(encoderValueTI < 127){
          encoderValueTI++;
        }           
        sendMidiMsg(0xB0, 11 +modeEncoder, encoderValueTI);            
        oldPos_TI = neuePosition;  
      }
      else if(neuePosition < oldPos_TI - 3){
        if(encoderValueTI > 0){              
          encoderValueTI--;
        }
        sendMidiMsg(0xB0, 11 + modeEncoder, encoderValueTI);            
        oldPos_TI = neuePosition;              
      }
      modeValues[3][modeEncoder] = encoderValueTI;  
    }
}

void readEncoderWE(){    
  long neuePosition; 
  encoderValueWE = modeValues[4][modeEncoder];
  neuePosition = EncoderWE.read();  
    if (neuePosition != oldPos_WE)
    {
      if (neuePosition > oldPos_WE + 3){
        if(encoderValueWE < 127){
          encoderValueWE++;
        }           
        sendMidiMsg(0xB0, 13 +modeEncoder, encoderValueWE);            
        oldPos_WE = neuePosition;  
      }
      else if(neuePosition < oldPos_WE - 3){
        if(encoderValueWE > 0){              
          encoderValueWE--;
        }
        sendMidiMsg(0xB0, 13 + modeEncoder, encoderValueWE);            
        oldPos_WE = neuePosition;              
      }
      modeValues[4][modeEncoder] = encoderValueWE;  
    }
}

void readEncoderSW(){    
  long neuePosition; 
  encoderValueSW = modeValues[5][modeEncoder];
  neuePosition = EncoderSW.read();  
    if (neuePosition != oldPos_SW)
    {
      if (neuePosition > oldPos_SW + 3){
        if(encoderValueSW < 127){
          encoderValueSW++;
        }           
        sendMidiMsg(0xB0, 15 +modeEncoder, encoderValueSW);            
        oldPos_SW = neuePosition;  
      }
      else if(neuePosition < oldPos_SW - 3){
        if(encoderValueSW > 0){              
          encoderValueSW--;
        }
        sendMidiMsg(0xB0, 15 + modeEncoder, encoderValueSW);            
        oldPos_SW = neuePosition;              
      }
      modeValues[5][modeEncoder] = encoderValueSW;  
    }
}

void readEncoderST(){    
  long neuePosition; 
  encoderValueST = modeValues[6][modeEncoder];
  neuePosition = EncoderST.read();  
    if (neuePosition != oldPos_ST)
    {
      if (neuePosition > oldPos_ST + 3){
        if(encoderValueST < 127){
          encoderValueST++;
        }           
        sendMidiMsg(0xB0, 17 +modeEncoder, encoderValueST);            
        oldPos_ST = neuePosition;  
      }
      else if(neuePosition < oldPos_ST - 3){
        if(encoderValueST > 0){              
          encoderValueST--;
        }
        sendMidiMsg(0xB0, 17 + modeEncoder, encoderValueST);            
        oldPos_ST = neuePosition;              
      }
      modeValues[6][modeEncoder] = encoderValueST;  
    }
}

void readEncoderKL(){    
  long neuePosition; 
  encoderValueKL = modeValues[7][modeEncoder];
  neuePosition = EncoderKL.read();  
    if (neuePosition != oldPos_KL)
    {
      if (neuePosition > oldPos_KL + 3){
        if(encoderValueKL < 127){
          encoderValueKL++;
        }           
        sendMidiMsg(0xB0, 19 +modeEncoder, encoderValueKL);            
        oldPos_KL = neuePosition;  
      }
      else if(neuePosition < oldPos_KL - 3){
        if(encoderValueKL > 0){              
          encoderValueKL--;
        }
        sendMidiMsg(0xB0, 19 + modeEncoder, encoderValueKL);            
        oldPos_KL = neuePosition;              
      }
      modeValues[7][modeEncoder] = encoderValueKL;  
    }
}
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
void loop() {
  // put your main code here, to run repeatedly:
  if(Serial1.available() >= 4){
    byte bytes[4] = {0,0,0,0};
    for(int i=0; i<4; i++){
      bytes[i] = Serial1.read();
    }
    getMidiMsg(bytes);
  }
  
  readNano();
  readEncoder();
  EncoderClicks();
  
  if(modeEncoder == 0){
    pixels.setPixelColor(12, pixels.Color(60, 255, 0));
    pixels.show();
      }
  else if(modeEncoder == 1){
    pixels.setPixelColor(12, pixels.Color(120, 40, 120));
    pixels.show();
      }
  if(modeColorEncoder == 0){
    pixels.setPixelColor(13, pixels.Color(60, 255, 0));
    pixels.show();
      }
  else if(modeColorEncoder == 1){
    pixels.setPixelColor(13, pixels.Color(120, 40, 120));
    pixels.show();
      }
  else if(modeColorEncoder == 2){
    pixels.setPixelColor(13, pixels.Color(0, 180, 90));
    pixels.show();
  }
  setEncLed();
  //if(timer + 300 < millis()){
    //setTwelveButtonsColor(white);
  //}
 // if(timer + 3000 < millis()){
  //  printHomeScreen("LOOOOOOOOL");
  //  timer = millis();
 // } 
 // if(displayCheck){
//    printHomeScreen(msgString);
 //   displayCheck = false;
 //   timer = millis();
 // } 
}

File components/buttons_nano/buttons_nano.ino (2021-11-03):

#include <Bounce2.h>
#include <Encoder.h>

int modeColorEncoder = 0;

int modeValuesColor[2][3] = { 64 };

byte msgFromMega[4];


//int button1 = A6;
int button2 = 10;
int button3 = A5;
int button4 = A4;
int button5 = A3;
int button6 = A2;
int button7 = 2;
int button8 = 3;
int button9 = 4;
int button10 = 5;
int button11 = 6;
int button12 = 7;
int button13 = 8;
int button14 = 9;

//bool bb1 = false;
bool bb2 = false;
bool bb3 = false;
bool bb4 = false;
bool bb5 = false;
bool bb6 = false;
bool bb7 = false;
bool bb8 = false;
bool bb9 = false;
bool bb10 = false;
bool bb11 = false;
bool bb12 = false;
bool bb13 = false;
bool bb14 = false;

//Bounce b1 = Bounce(button1, 10);
Bounce b2 = Bounce(button2, 10);
Bounce b3 = Bounce(button3, 10);
Bounce b4 = Bounce(button4, 10);
Bounce b5 = Bounce(button5, 10);
Bounce b6 = Bounce(button6, 10);
Bounce b7 = Bounce(button7, 10);
Bounce b8 = Bounce(button8, 10);
Bounce b9 = Bounce(button9, 10);
Bounce b10 = Bounce(button10, 10);
Bounce b11 = Bounce(button11, 10);
Bounce b12 = Bounce(button12, 10);
Bounce b13 = Bounce(button13, 10);
Bounce b14 = Bounce(button14, 10);

//J26
const int CLK_J26 = 12;      
const int DT_J26 = 13;// auf pin 13 ändern
long oldPos_J26 = -999;
Encoder EncoderJ26(DT_J26,CLK_J26);
int encoderValueJ26;

//J27
const int CLK_J27 = 11;      
const int DT_J27 = A1;
long oldPos_J27 = -999;
Encoder EncoderJ27(DT_J27,CLK_J27);
int encoderValueJ27;

void readEncoderJ26(){    
  long neuePosition; 
  encoderValueJ26 = modeValuesColor[0][modeColorEncoder];
  neuePosition = EncoderJ26.read();  
    if (neuePosition != oldPos_J26)
    {
      if (neuePosition > oldPos_J26 + 3){
        if(encoderValueJ26 < 127){
          encoderValueJ26++;
        }           
        sendMidiMsg(1, 0xB0, 47 +modeColorEncoder, encoderValueJ26);            
        oldPos_J26 = neuePosition;  
      }
      else if(neuePosition < oldPos_J26 - 3){
        if(encoderValueJ26 > 0){              
          encoderValueJ26--;
        }
        sendMidiMsg(1, 0xB0, 47 + modeColorEncoder, encoderValueJ26);            
        oldPos_J26 = neuePosition;              
      }
      modeValuesColor[0][modeColorEncoder] = encoderValueJ26;  
    }
}

void readEncoderJ27(){    
  long neuePosition; 
  encoderValueJ27 = modeValuesColor[1][modeColorEncoder];
  neuePosition = EncoderJ27.read();  
    if (neuePosition != oldPos_J27)
    {
      if (neuePosition > oldPos_J27 + 3){
        if(encoderValueJ27 < 127){
          encoderValueJ27++;
        }           
        sendMidiMsg(1 ,0xB0, 50 +modeColorEncoder, encoderValueJ27);            
        oldPos_J27 = neuePosition;  
      }
      else if(neuePosition < oldPos_J27 - 3){
        if(encoderValueJ27 > 0){              
          encoderValueJ27--;
        }
        sendMidiMsg(1,0xB0, 50 + modeColorEncoder, encoderValueJ27);            
        oldPos_J27 = neuePosition;              
      }
      modeValuesColor[1][modeColorEncoder] = encoderValueJ27;  
    }
}

void getEncoderValues(){
  if(Serial.available() >= 4){
    for(int i=0; i<4; i++){
      msgFromMega[i] = Serial.read();
    }
    if(msgFromMega[0] == 1 && msgFromMega[1] == 1 && msgFromMega[2] == 1){
      modeColorEncoder = msgFromMega[3];
    }
    else if(msgFromMega[2] < 50){
      modeValuesColor[0][modeColorEncoder] = msgFromMega[3];
    }
    else{
      modeValuesColor[1][modeColorEncoder] = msgFromMega[3];
    }
  }
}

void sendMidiMsg(byte state, byte channel, byte mode, byte velocity){
  byte tmp[] = {state, channel, mode, velocity};
  Serial.write(tmp, 4);
}

void setup() {
  // put your setup code here, to run once:
  
 // pinMode(button1, INPUT);  
  pinMode(button2, INPUT);
  pinMode(button3, INPUT);
  pinMode(button4, INPUT);
  pinMode(button5, INPUT);
  pinMode(button6, INPUT);
  pinMode(button7, INPUT);
  pinMode(button8, INPUT);
  pinMode(button9, INPUT);
  pinMode(button10, INPUT);
  pinMode(button11, INPUT);
  pinMode(button12, INPUT);
  pinMode(button13, INPUT);
  pinMode(button14, INPUT);
  Serial.begin(9600);
}

void loop() {
  //if(b1.update()){
    //if(!bb1){
     // byte msg[4] = {5, 1, 10, 10};
     // Serial.write(msg, 4);
     // bb1 = true; 
    //}
   // else{
   //   bb1 = false;
   // }
 // }
  if(b2.update()){
    if(!bb2){
      byte msg[4] = {5, 2, 10, 10};
      Serial.write(msg, 4);
      bb2 = true; 
    }
    else{
      bb2 = false;
    }
  }
  if(b3.update()){
    if(!bb3){
      byte msg[4] = {5, 3, 10, 10};
      Serial.write(msg, 4);
      bb3 = true; 
    }
    else{
      bb3 = false;
    }
  }
  if(b4.update()){
    if(!bb4){
      byte msg[4] = {5, 4, 10, 10};
      Serial.write(msg, 4);
      bb4 = true; 
    }
    else{
      bb4 = false;
    }
  }
  if(b5.update()){
    if(!bb5){
      byte msg[4] = {5, 5, 10, 10};
      Serial.write(msg, 4);
      bb5 = true; 
    }
    else{
      bb5 = false;
    }
  }
  if(b6.update()){
    if(!bb6){
      byte msg[4] = {5, 6, 10, 10};
      Serial.write(msg, 4);
      bb6 = true; 
    }
    else{
      bb6 = false;
    }
  }
  if(b7.update()){
    if(!bb7){
      byte msg[4] = {5, 7, 10, 10};
      Serial.write(msg, 4);
      bb7 = true; 
    }
    else{
      bb7 = false;
    }
  }
  if(b8.update()){
    if(!bb8){
      byte msg[4] = {5, 8, 10, 10};
      Serial.write(msg, 4);
      bb8 = true; 
    }
    else{
      bb8 = false;
    }
  }
  if(b9.update()){
    if(!bb9){
      byte msg[4] = {5, 9, 10, 10};
      Serial.write(msg, 4);
      bb9 = true; 
    }
    else{
      bb9 = false;
    }
  }
  if(b10.update()){
    if(!bb10){
      byte msg[4] = {5, 10, 10, 10};
      Serial.write(msg, 4);
      bb10 = true; 
    }
    else{
      bb10 = false;
    }
  }
  if(b11.update()){
    if(!bb11){
      byte msg[4] = {5, 11, 10, 10};
      Serial.write(msg, 4);
      bb11 = true; 
    }
    else{
      bb11 = false;
    }
  }
  if(b12.update()){
    if(!bb12){
      byte msg[4] = {5, 12, 10, 10};
      Serial.write(msg, 4);
      bb12 = true; 
    }
    else{
      bb12 = false;
    }
  }
  if(b13.update()){
    if(!bb13){
      byte msg[4] = {5, 13, 10, 10};
      Serial.write(msg, 4);
      bb13 = true; 
    }
    else{
      bb13 = false;
    }
  }
  if(b14.update()){
    if(!bb14){
      byte msg[4] = {5, 14, 10, 10};
      Serial.write(msg, 4);
      bb14 = true; 
    }
    else{
      bb14 = false;
    }
  }
  readEncoderJ26();
  readEncoderJ27();
  getEncoderValues();
}

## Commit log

2021-11-03 STL Files added
    [1BEF.stl, 1CMODE.stl, 1M1.stl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]
2021-11-03 schematics added
